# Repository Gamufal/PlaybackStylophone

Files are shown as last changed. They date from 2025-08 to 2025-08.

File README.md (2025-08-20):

# PlaybackStylophone
Stylofon oparty na mikrokontrolerze z możliwością odtworzenia zapisanego wcześniej utworu.

## Cel projektu
Celem jest samodzielne zaprojektowanie i wykonanie własnej wersji stylofonu opartego na mikrokontrolerze, zainspirowanej klasycznym instrumentem elektronicznym z ubiegłego wieku, a jednocześnie wzbogaconej o możliwości, jakie daje współczesna technologia cyfrowa. Realizacja urządzenia ma na celu rozwinięcie umiejętności z zakresu elektroniki, programowania oraz syntezy dźwięku.

## Funkcjonalności:
- Generowanie elektronicznego dźwięku o stałej, syntetycznej barwie
- Regulacja głośności dźwięku
- Regulacja wysokości tonu
- Nagrywanie utworu muzyczneczo
- Odtwarzanie wcześniej nagranej kompozycji
- Zapisywanie ustawień i utworu do pamięci  
- Prezentowanie informacji na wbudowanym wyświetlaczu
- Intuicyjna obsługa ekranu za pomocą przycisków 
- Przenośność dzięki wbudowanemu zasilaniu bateryjnemu
- Szybki start i gotowość do grania po uruchomieniu
- Modułowość umożliwiająca łatwą naprawę w razie uszkodzenia komponentów

## Płytka drukowana
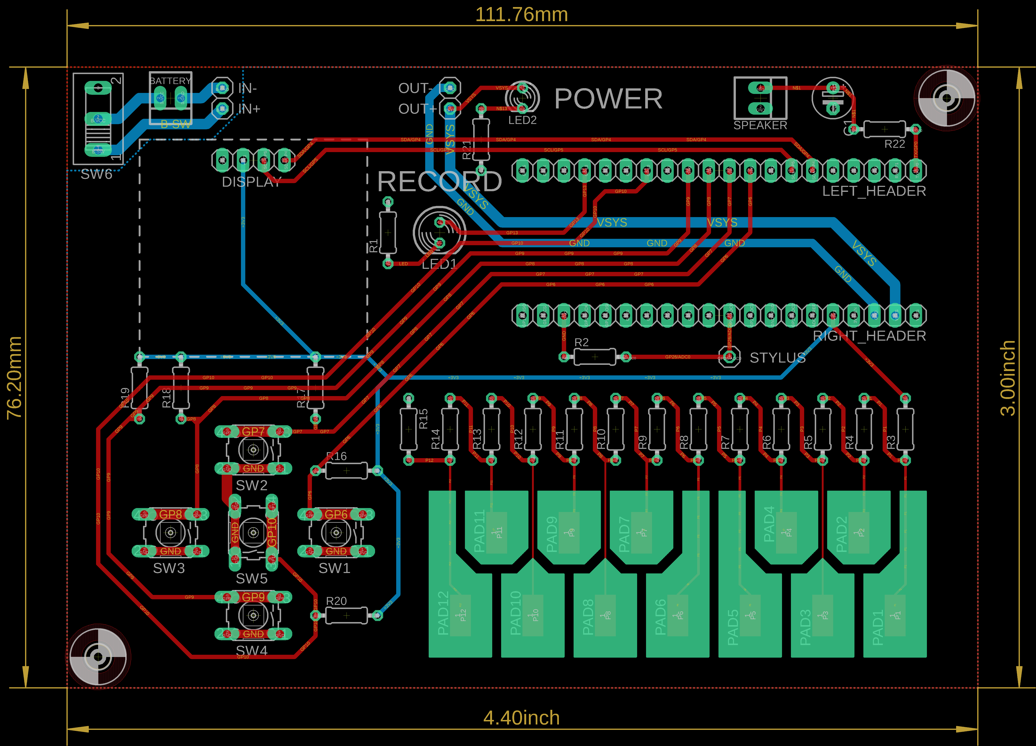
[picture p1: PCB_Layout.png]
PCB Layout


## Mikrokontroler 
Urządzenie wykorzystuje [Raspberry Pi Pico 2](https://www.raspberrypi.com/products/raspberry-pi-pico-2). 

## Kompatybilność
Urządzenie jest kompatybilne z wszystkimi mikrokontrolerami serii Pico od Raspberry Pi. 

## Jak uruchomić urządzenie?
1.	Podłącz baterię 9V typu 6LR61 do gniazda zasilania.
2.	Włącz urządzenie za pomocą przełącznika zlokalizowanego w prawym górnym rogu obudowy.
3.	Po włączeniu:
    - Zapali się zielona dioda LED.
    - Aktywuje się ekran wyświetlacza.
4.	Urządzenie jest gotowe do pracy.
5.	Aby wygenerować dźwięk, dotknij metalowego klawisza przy pomocy stylusu, zostanie odtworzony odpowiedni ton muzyczny.

## Autor
Kamil Kotorc - *Gamufal*

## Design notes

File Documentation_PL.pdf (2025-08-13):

Kamil Kotorc | 31.07.2025

# Stylofon z możliwością nagrywania utworów

## Dokumentacja projektu

### Cel projektu

Celem jest samodzielne zaprojektowanie i wykonanie własnej wersji stylofonu opartego na mikrokontrolerze, zainspirowanej klasycznym instrumentem elektronicznym z ubiegłego wieku, a jednocześnie wzbogaconej o możliwości, jakie daje współczesna technologia cyfrowa. Realizacja urządzenia ma na celu rozwinięcie umiejętności z zakresu elektroniki, programowania oraz syntezy dźwięku.

### Opis głównych założeń projektu

- Stylofon to przenośny instrument muzyczny generujący elektroniczny dźwięk o stałej, syntetycznej barwie, przypominający brzmienie prostych syntezatorów.
- Dzięki wbudowanemu źródłu zasilania, urządzenie jest łatwe do przenoszenia i można je zabrać w dowolne miejsce.
- Instrument wyposażony jest w metalową klawiaturę, która reaguje na nacisk stylusu, zamykając obwód i generując dźwięk.
- Stylofon umożliwia regulację wysokości dźwięku, co daje użytkownikowi większą swobodę twórczą.
- Użytkownik ma możliwość nagrywania swoich utworów muzycznych oraz ich późniejszego odtwarzania.
- Mały wyświetlacz zwiększa intuicyjność obsługi urządzenia, ułatwiając korzystanie z jego funkcji.
- Urządzenie jest zasilane bateryjnie, co eliminuje konieczność stałego podłączenia do źródła prądu.

Copyright: © 2025 Kamil Kotorc | 1

## Spis treści

# Wybór elementów elektronicznych

## Mikrokontroler

Większość z wymienionych mikrokontrolerów byłaby odpowiednia do realizacji tego projektu, jednak należy zwrócić uwagę na kilka kluczowych aspektów. ESP32, choć oferuje największą moc obliczeniową, charakteryzuje się stosunkowo wysokim zużyciem energii, co ogranicza jego czas pracy na baterii. Układy Arduino są relatywnie drogie, Mega oferuje nieznacznie większe możliwości niż wersja Nano, głównie w zakresie liczby pinów GPIO, które nie są tak ważne w tym projekcie. Mój wybór padł na Raspberry Pi Pico 2 ze głównie ze względu na sporą uniwersalność. Cechuje się dobrymi parametrami, obsługiwanymi interfejsami oraz 12-bit rozdzielczością ADC, który jest ważnym elementem projektu. Ponadto stosunek jakości do ceny jest zadowalający.

## Wyświetlacz

Postanowiłem użyć wyświetlacza typu OLED. Jego główną zaletą jest dobra rozdzielczość w stosunku do jego małych rozmiarów, przez co idealnie wpasuje się w urządzenie. Dodatkowo jest tani i wymaga tylko 2 pinów do komunikacji z mikrokontrolerem, a jego niski czas odświeżania przełoży się na lepszą responsywność urządzenia. Także w stosunku do innych wyświetlaczy posiada dobry kontrast, a co za tym idzie oferuje dobrą czytelność o każdej porze dnia.

## Przetwornica napięcia

Zastosowałem popularny układ LM2596. Cechuje się wysoką sprawnością, co wydłuży pracę na baterii. Dodatkowo posiada zabezpieczenia chroniące urządzenie oraz wystarczającą moc do zasilania urządzenia. Występuje także w wielu konfiguracjach, w szczególności wersje o małych rozmiarach.

## Metalowa klawiatura

Wzorując się na oryginalnym stylofonie, stwierdziłem, że dobrym rozwiązaniem będzie wykorzystanie drabinki rezystorowej i odczytywanie różnicy spadku napięcia względem napięcia referencyjnego. Wadą tej metody jest niepowtarzalność otrzymywanych wartości napięć, co należy uwzględnić podczas programowania. Zaletą jest natomiast to, że wymaga ona użycia jedynie jednego portu analogowego. Wybrany mikrokontroler posiada 12-bit ADC, który bez problemu dokładnie zmierzy wartości odpowiadające każdemu klawiszowi. Same klawisze można stworzyć poprzez rozdzielenie powierzchni na płytce na poszczególne klawisze. Do tego posłużyła mi miedziana płytka do wytrawiania.

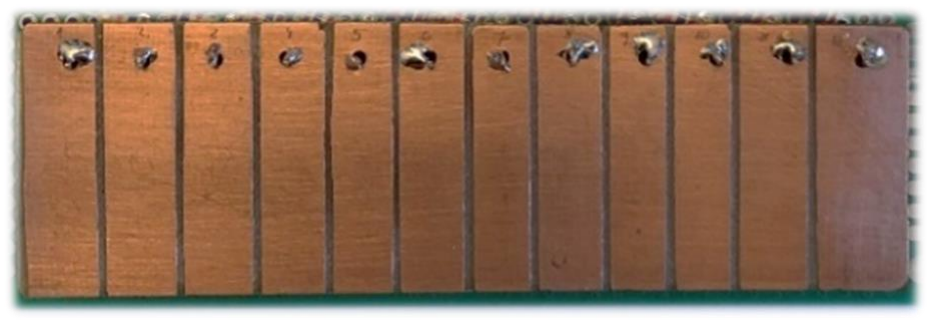
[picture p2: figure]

PROTOTYPOWA KLAWIATURA WYKONANA NA LAMINACIE 1,6MM

# Specyfikacja wewnętrzna urządzenia

## Generowanie dźwięku

Wstęp
Stylofon pierwotnie wyprodukowany w Wielkiej Brytanii w 1968 roku. Opierał się na programowalnym tranzystorze jednozłączowym UJT, który nadawał jego unikalne brzmienie. W latach 70-tych całkowicie zastąpiono oscylatory relaksacyjne prostszymi i tańszymi generatorami tonów prostokątnych opartymi na timerze 555.
Wersja z UJT
Układ oparty na tranzystorze jednozłączowym, ma zalety głównie w postaci otrzymywanego charakterystycznego i oryginalnego brzmienia, a sama konstrukcja nie jest stosunkowo skomplikowana.

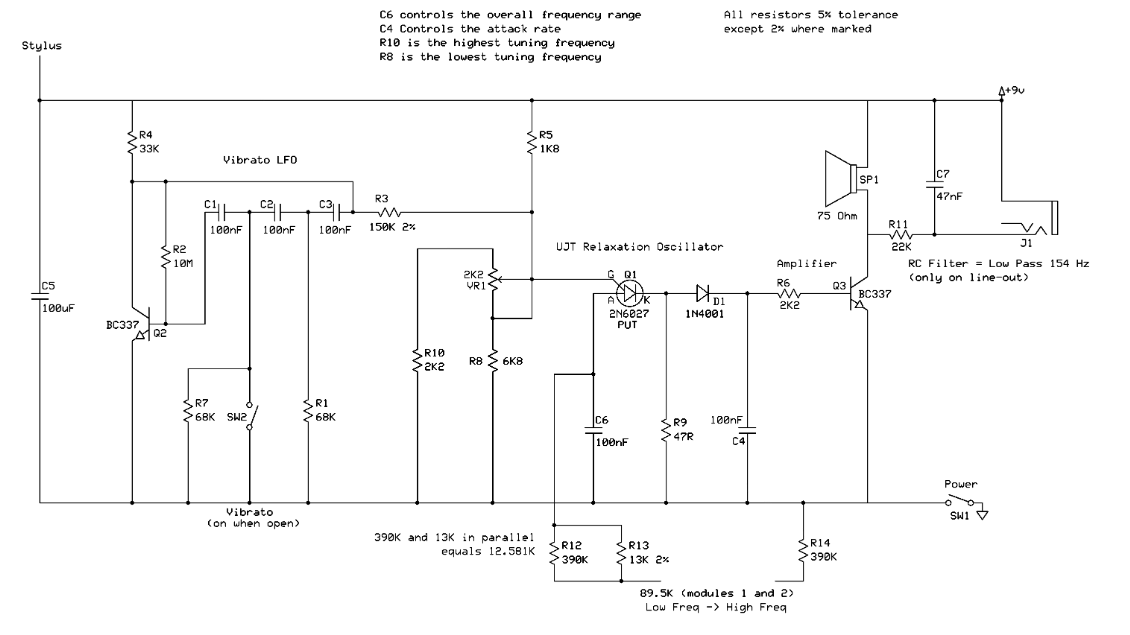
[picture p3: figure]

SCHEMAT ORYGINALNEGO STYLOFONU Z 1968

Jednak rozwiązanie to ma też swoje wady.
Oscylatory z tranzystorami jednozłączowymi są bardziej podatne na zmiany częstotliwości wynikające z wahań napięcia zasilania oraz tolerancji elementów pasywnych, co utrudnia precyzyjne dostrajanie generowanej częstotliwości bez specjalistycznego sprzętu, takiego jak oscyloskop.
UJT nie generuje sygnału o prostokątnym kształcie, co może wymagać zastosowania dodatkowych układów dopasowujących, aby przetwornik analogowo-cyfrowy mikrokontrolera mógł prawidłowo interpretować sygnał wejściowy.
Także rynek elektroniczny mocno się rozwinął, co za tym idzie dobranie odpowiedniego tranzystora jednozłączowego staje się trudniejsze, ponieważ wiele układów w nowszej technologii wyparło je z rynku.

Wersja z timerem 555
Nowsze rozwiązania są oparte na timerze 555, który jest jednym z najpopularniejszych i najbardziej wszechstronnych układów, które kiedykolwiek wyprodukowano. Częstotliwość oscylacji jest regulowana, a możliwe jest nawet dodanie różnych efektów, gdyż układ jest w stanie generować różne kształty fali.

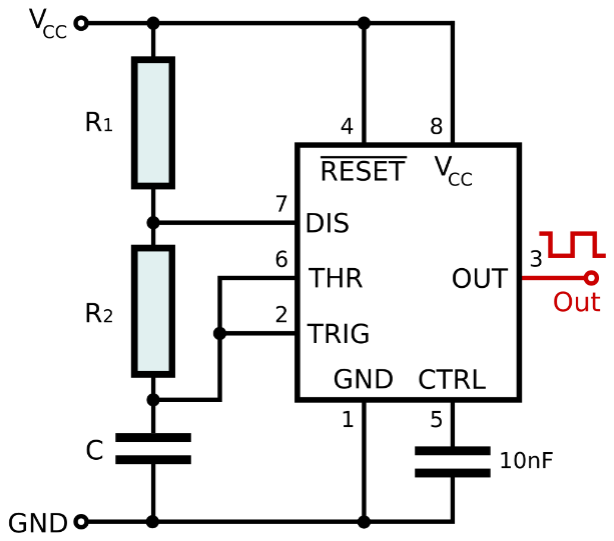
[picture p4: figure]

SCHEMAT UKŁADU ASTABILNEGO

Mimo tych zalet rozwiązanie to ma swoje ograniczenia. Nadal wymagana jest integracja z mikrokontrolerem, w celu odczytania generowanej częstotliwości. Timer 555 operuje na napięciu od 4.5 do 16 wolt, co może okazać się zbyt wysokim napięciem dla przetworników ADC większości mikrokontrolerów, bez zastosowania układów redukujących napięcie. Również z poziomu mikrokontrolera nie możemy cyfrowo sterować jaka częstotliwość powinna być wygenerowana w 555, gdyż ta zależna jest od rezystancji pomiędzy jego pinami.
Wersja PWM
Zamiast korzystać z dedykowanych układów, większość mikrokontrolerów pozwala na generowanie fali prostokątnej za pomocą sygnału PWM. Wybrałem zatem takie rozwiązanie, bo znacząco upraszcza konstrukcję, a częstotliwość i wypełnienie sygnału można sterować programowo.

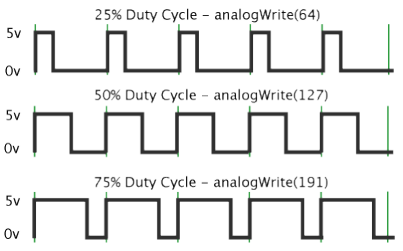
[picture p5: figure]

SYGNAŁ GENEROWANY PRZY UŻYCIU PWM

Wadą tego rozwiązania jest jednak jakość generowanych tonów, ponieważ funkcja PWM nie jest zoptymalizowana pod kątem sygnałów audio. Niemożliwe jest też wytworzenie innych kształtów fali niż prostokątna samym mikrokontrolerem. Natomiast jakość dźwięku nie będzie tutaj problemem.

## Schemat blokowy

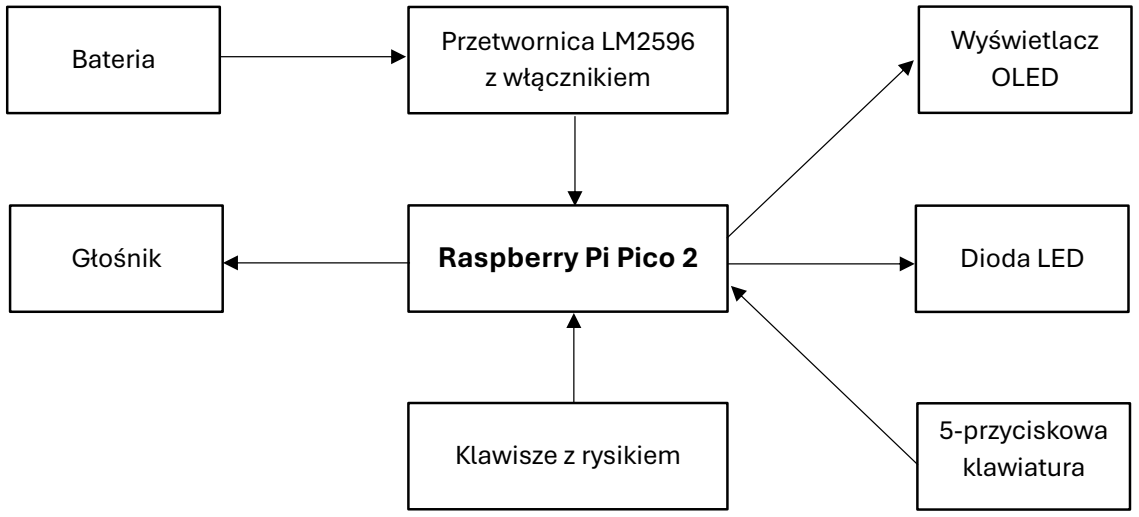
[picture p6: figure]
Wyświetlacz OLED; 5-przyciskowa klawiatura; Raspberry Pi Pico 2; Klawisze z rysikiem; Bateria; Przetwornica LM2596; z włącznikiem; Głośnik; Dioda LED

Opis poszczególnych bloków
Raspberry Pi Pico 2 – Serce urządzenia, odpowiedzialne za przetwarzanie danych wejściowych i wyjściowych, generowanie sygnału dźwiękowego oraz integrację wszystkich elementów urządzenia. Przechowuje dane, takie jak ustawienia, pamięć programu oraz zapisane utwory. Wyświetlacz OLED – Jedno-calowy wyświetlacz odpowiedzialny za prezentowanie informacji z mikrokontrolera oraz komunikację z użytkownikiem. Zwiększa intuicyjność obsługi urządzenia i wyświetla menu z różnymi opcjami.
Dioda LED – Czerwona dioda, która zwiększa intuicyjność obsługi urządzenia. Migocze podczas nagrywania, a świeci na stałe podczas odtwarzania utworów, dopełniając wyświetlacz. 5-przyciskowa klawiatura – Umożliwia zbieranie danych od użytkownika i służy do nawigacji po elementach wyświetlanych na ekranie OLED.
Klawisze z rysikiem – Po zetknięciu zamykają obwód, przesyłając do mikrokontrolera informację o naciśniętym klawiszu.
Głośnik – Mimo niewielkiej mocy (1W), generuje wyraźny dźwięk, przesyłany z mikrokontrolera. Bateria – Standardowa bateria 9V stanowi główne źródło zasilania urządzenia. Dzięki dwóm charakterystycznym wejściom jest łatwa do wymiany, a przy tym kompaktowa.
Przetwornica LM2596 – Obniża napięcie z 9V do 3,3V, akceptowalnego przez mikrokontroler, i zasila pozostałe elementy znajdujące się na płytce.

## Schemat ideowy

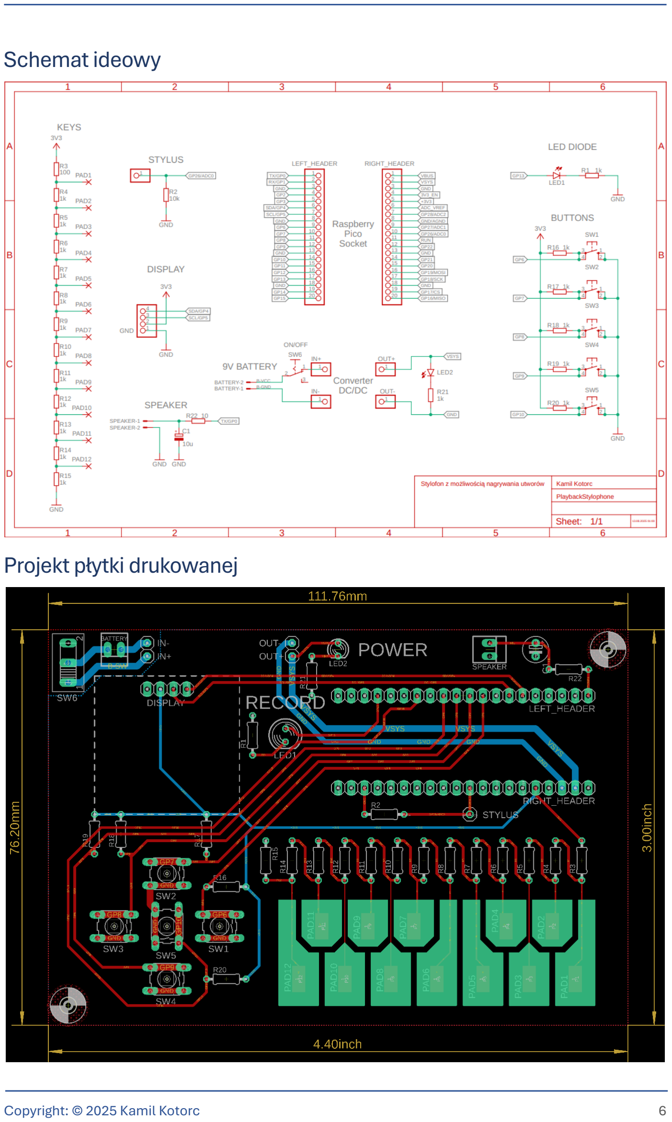
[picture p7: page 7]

## Projekt płytki drukowanej

## Lista elementów

NAZWA | ILOŚĆ
Raspberry Pi Pico 2 | 1
Dioda LED 5mm | 2
Rezystor 1/4W 1kΩ | 21
Rezystor 1/4W 10kΩ | 1
Wyświetlacz OLED 0,96'' | 1
Przetwornica step-down LM2596 | 1
Tact Switch 6x6mm | 5
Złącza damskie goldpin | 5
Mikroprzełącznik bistabilny | 1
Bateria 9V 4022 6LR61 | 1
Głośnik 1W 8Ohm | 1

## Oprogramowanie urządzenia

Algorytm działania oprogramowania
Oprogramowanie stylofonu działa w pętli głównej, zarządza dźwiękiem, wyświetlaczem oraz interakcją z użytkownikiem. Pozwala na zmianę parametrów, nagrywanie oraz odtwarzanie dźwięków.
Główne etapy działania to:
1. Inicjalizacja urządzeń peryferyjnych:
- OLED
- Przyciski
- ADC
- PWM
- dioda LED
2. Wczytanie zapisanych ustawień z pliku settings.json.
3. Uruchomienie pętli menu głównego, pozwalającej użytkownikowi na wybór opcji.
4. Obsługa wybranych funkcji:
- Regulacja głośności
- Zmiana oktawy
- Nagrywanie dźwięku
- Odtwarzanie nagrania
5. Dynamiczne odtwarzanie dźwięków na podstawie wartości z czujnika ADC.
6. Zapis ustawień do pliku.

Opis zmiennych
volume – Poziom głośności (zakres 1-8).
tone – Wybór oktawy (1 – dolna, 2 – środkowa, 3 – górna).
recording – Lista przechowująca zapisane dźwięki w postaci par (częstotliwość, czas). adc_thresholds – Progi wartości ADC dla przypisania konkretnej nuty.

lower_octave, middle_octave, higher_octave – Tablice częstotliwości dźwięków dla
różnych oktaw.

Opis funkcji
save_single_setting(key, value) – Zapisuje pojedyncze ustawienie do pliku settings.json.
load_settings() – Wczytuje ustawienia zapisane w settings.json, jeśli plik istnieje. get_note_index(adc_val) – Na podstawie wartości ADC zwraca indeks odpowiadający konkretnej nucie.
get_note_from_index(idx) – Zwraca częstotliwość dźwięku na podstawie indeksu i aktualnej oktawy.
update_live_audio() – Odczytuje wartość ADC i generuje odpowiadający jej dźwięk poprzez PWM.
display_menu(selected_item) – Wyświetla główne menu na ekranie OLED, podświetlając wybraną opcję.
volume_menu() – Obsługuje zmianę głośności i zapisuje ustawienie.
tone_menu() – Obsługuje zmianę oktawy i zapisuje ustawienie.
record_menu() – Nagrywa dźwięki grane na stylofonie, zapisując je w tablicy recording. play_menu() – Odtwarza zapisane dźwięki poprzez generowanie odpowiednich częstotliwości PWM.
main() – Główna pętla obsługująca nawigację po menu oraz reakcję na wybór użytkownika.

Szczegółowy opis kluczowej procedury

update_live_audio()
1. Odczytuje wartość ADC.
2. Sprawdza, czy wartość ADC odpowiada progowi nuty.
3. Jeśli tak, odczytuje częstotliwość z aktualnie wybranej oktawy.
4. Ustawia częstotliwość PWM na wyliczoną wartość.
5. Jeśli nie, wyłącza sygnał PWM.

# Specyfikacja zewnętrzna urządzenia

## Zdjęcie gotowego prototypu urządzenia

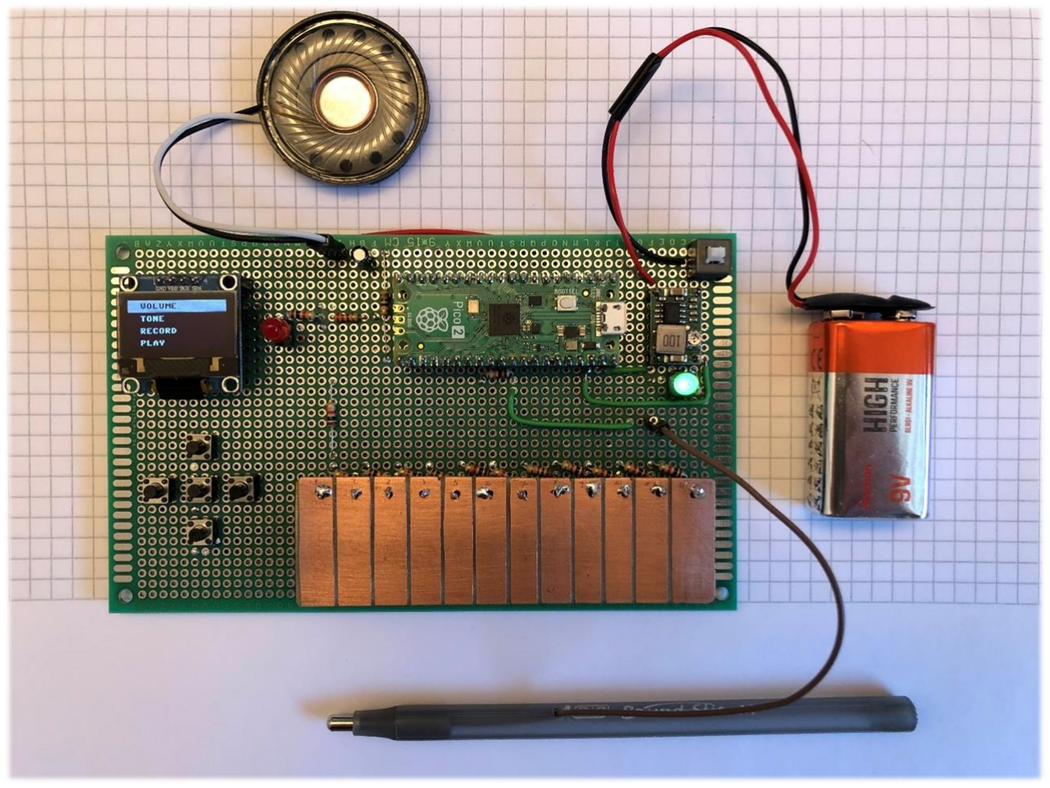
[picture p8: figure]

## Elementy sterujące

- 5-przyciskowa klawiatura w lewym dolnym rogu urządzenia
- Metalowe klawisze z stylusem w dolnej części urządzenia
- Włącznik urządzenia w prawym górnym rogu

## Elementy wykonawcze

- Wyświetlacz OLED po lewej stronie
- Czerwona dioda po prawej od wyświetlacza
- Zielona dioda w prawej części urządzenia
- Głośnik 1W znajdujący się w górnej części urządzenia

## Reakcja oprogramowania

Tabela przedstawiająca zachowanie urządzenia w odpowiedzi na działania użytkownika

Działanie użytkownika | Reakcja urządzenia
Włączenie urządzenia przełącznikiem | Zapala się zielona dioda LED
Dotknięcie metalowego klawisza stylusem | Wygenerowanie odpowiedniego tonu dźwiękowego
Naciśnięcie przycisku funkcyjnego | W zależności od przycisku:
- Nawigacja po menu
- Wybór opcji z menu
- Cofnięcie do menu głównego
- Ustawienie poziomu tonu lub głośności
- Rozpoczęcie nagrywania lub odtwarzania
Rozpoczęcie nagrywania utworu | Czerwona dioda miga
Rozpoczęcie odtwarzania nagranego utworu | Czerwona dioda świeci ciągłym światłem do końca odtwarzania

## Instrukcja obsługi urządzenia

Uruchomienie urządzenia
1. Podłącz baterię 9V typu 6LR61 do gniazda zasilania.
2. Włącz urządzenie za pomocą przełącznika zlokalizowanego w prawym górnym rogu obudowy.
3. Po włączeniu:
- Zapali się zielona dioda LED.
- Aktywuje się ekran wyświetlacza.
4. Urządzenie jest gotowe do pracy.
5. Aby wygenerować dźwięk, dotknij metalowego klawisza przy pomocy stylusu, zostanie odtworzony odpowiedni ton muzyczny.
Obsługa menu
Przycisk | Funkcja
Góra / Dół | Przejście do kolejnej/poprzedniej pozycji menu; cofnięcie do menu głównego.
Lewo / Prawo | Zmiana wartości parametru (głośność / tonacja).
Środkowy (OK) | Zatwierdzenie wyboru; uruchomienie funkcji (nagrywanie / odtwarzanie).

Potencjalne usterki i sposoby naprawy

Objaw | Możliwa przyczyna | Sugerowane rozwiązanie
Ekran działa, zielona dioda nie świeci | Przepalona zielona dioda LED | Wymień diodę na nową
Zielona dioda świeci, ekran nie działa | Uszkodzony moduł wyświetlacza | Sprawdź połączenia, w razie potrzeby wymień wyświetlacz
Ekran i zielona dioda nie działają | Rozładowana bateria 9V | Wymień baterię na nową
Dioda i ekran działają, ale urządzenie nie wydaje dźwięku | Uszkodzony głośnik lub jego połączenie | Sprawdź przewody głośnika lub wymień głośnik

## Programowanie układu

Programowanie układu następuje poprzez wpięcie kabla micro-USB do mikrokontrolera oraz podłączenie do komputera przy jednoczesnym trzymaniu przycisku BOOTSEL na mikrokontrolerze.

## Testowanie

Przed wykonaniem finalnej wersji urządzenia, stylofon został przetestowany na płytce prototypowej. Proces testowania obejmował następujące etapy:
1. Testowanie połączeń elektrycznych – Sprawdzono poprawność podłączenia wszystkich elementów. Wykorzystano multimetr do weryfikacji ciągłości obwodów i poprawnego doprowadzenia napięcia do poszczególnych komponentów.
2. Weryfikacja działania klawiatury i rysika – Testowano reakcję mikrokontrolera na naciśnięcie przycisków oraz dotknięcie rysikiem klawiszy. Sprawdzano, czy każda akcja skutkuje generowaniem odpowiedniego dźwięku.
3. Testowanie wyświetlacza OLED – Zweryfikowano poprawność komunikacji z mikrokontrolerem, wyświetlanie informacji oraz responsywność zmian w menu.
4. Sprawdzenie działania głośnika – Podawano różne częstotliwości dźwięku, aby upewnić się, że głośnik poprawnie generuje wymagane dźwięki.
5. Analiza pracy diody LED – Testowano miganie oraz ciągłe świecenie diody w zależności od aktywnego trybu pracy urządzenia.
6. Zasilanie i stabilność układu – Monitorowano pobór prądu oraz stabilność działania układu przy różnych obciążeniach. Testowano także wydajność przetwornicy LM2596, oraz wyregulowano ją do obniżenia napięcia do 3.32V.

# Odnośniki

- Strona projektu na GitHub (https://github.com/Gamufal/PlaybackStylophone)

# Literatura

Raspberry Pi Pico 2 Datasheet: An RP2350-based microcontroller board.
- © 2023-2024 Raspberry Pi Ltd

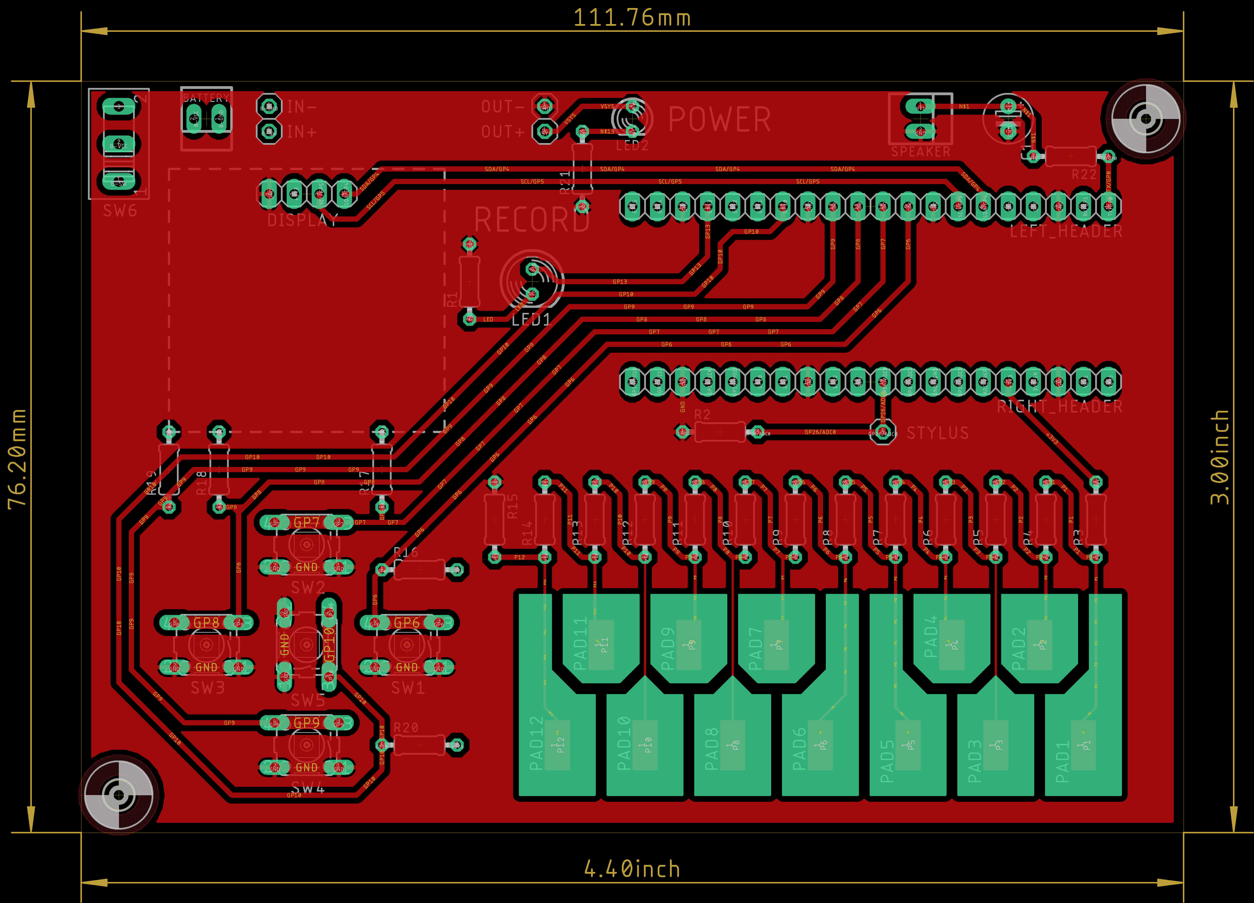
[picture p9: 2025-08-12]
PCB_TopLayer_Design.png

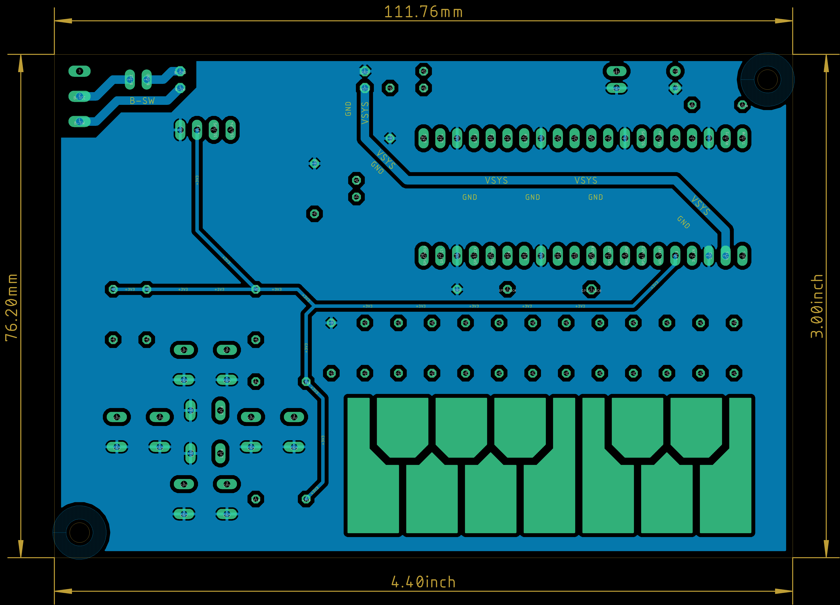
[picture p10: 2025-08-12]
PCB_BottomLayer_Design.png

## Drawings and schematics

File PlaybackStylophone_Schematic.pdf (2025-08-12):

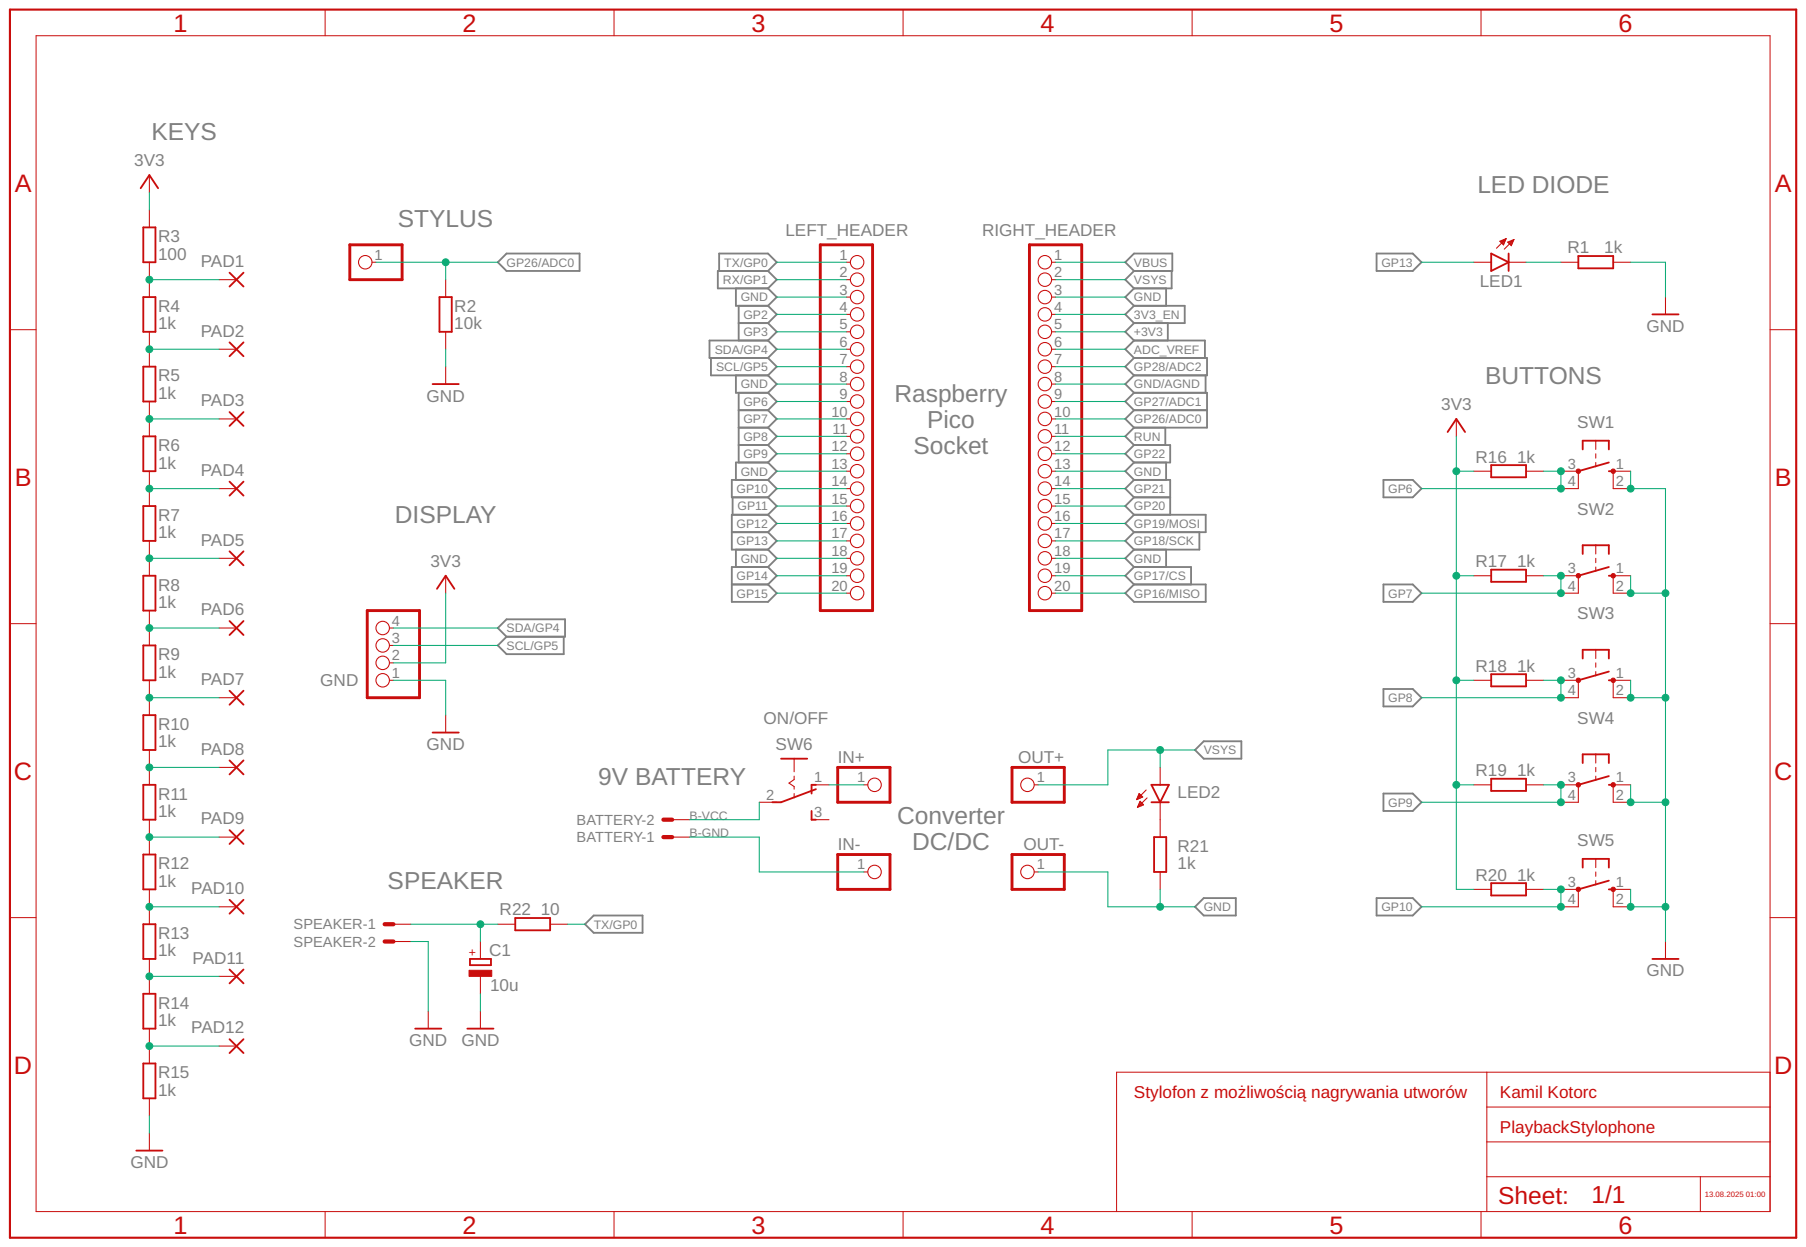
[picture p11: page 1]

RX/GP1 GP2 GP3 SDA/GP4
GND GND

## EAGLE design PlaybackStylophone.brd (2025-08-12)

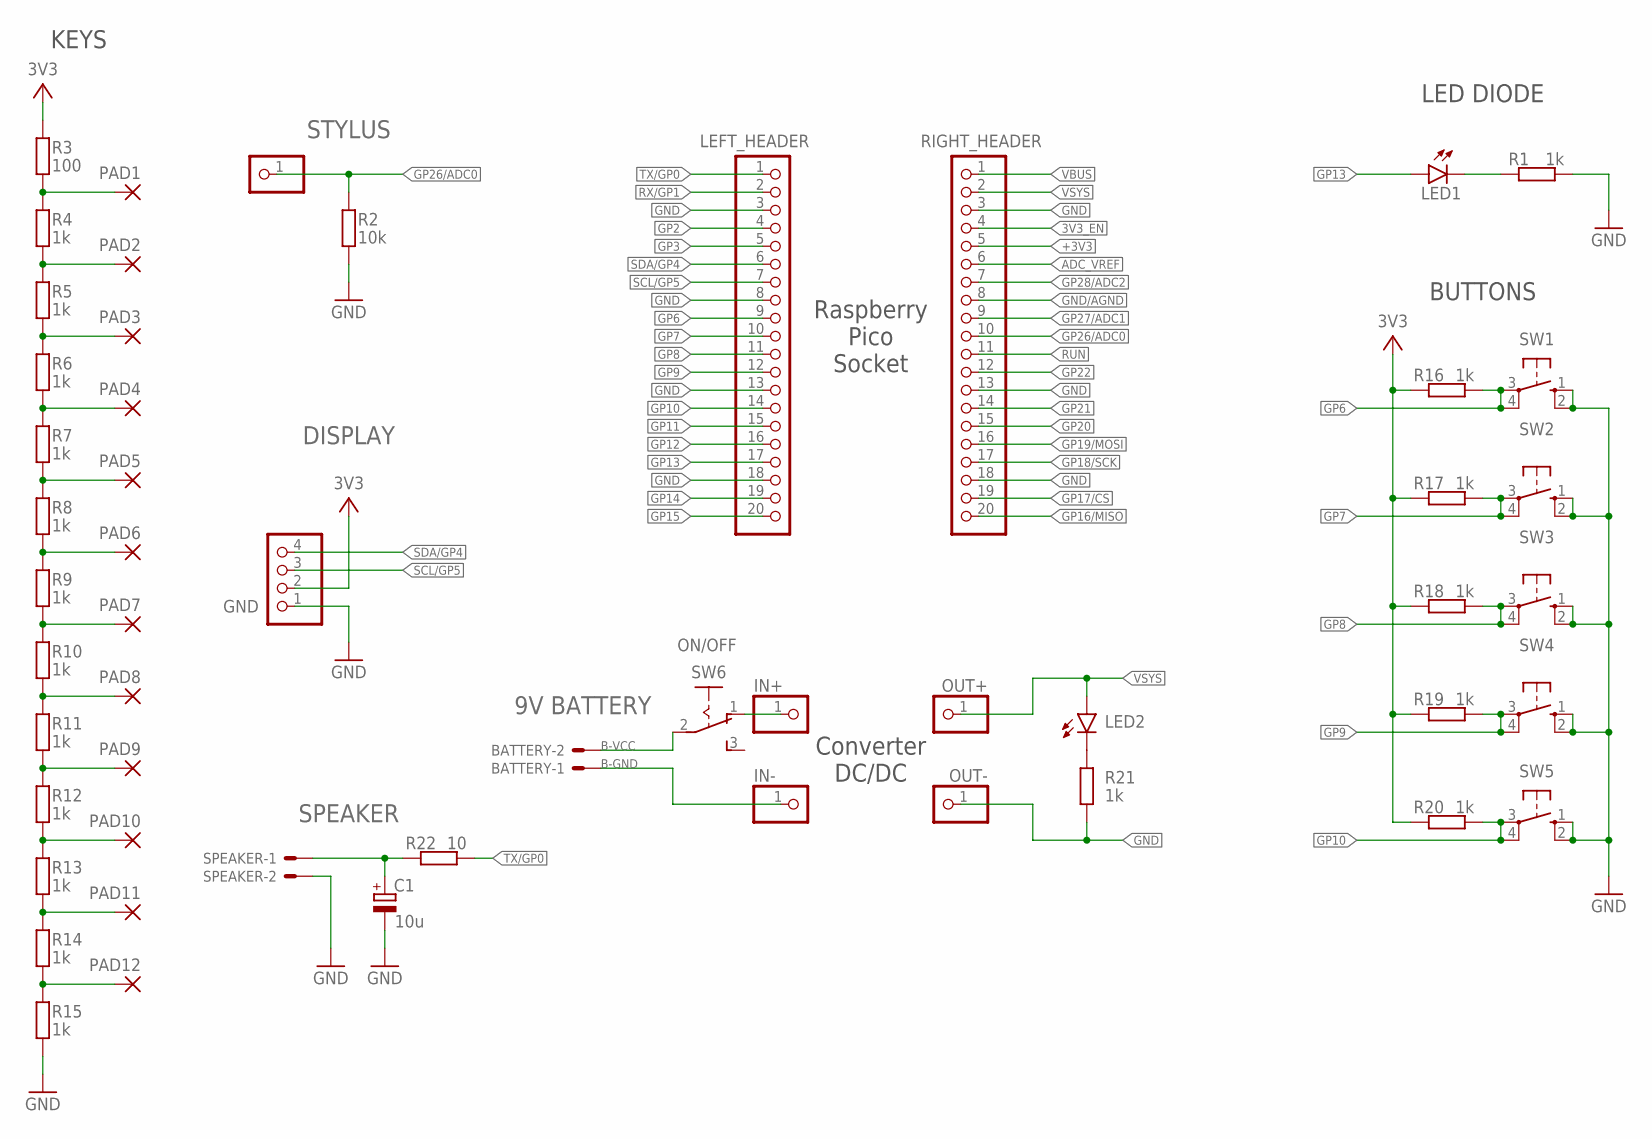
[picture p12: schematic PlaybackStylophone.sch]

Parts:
BATTERY: 9V BATTERY; 22-23-2021
C1: 10u; E2,5-5
DISPLAY: GND; 1X04
IN+: PINHD-1X1; 1X01
IN-: PINHD-1X1; 1X01
LED1: LED5MM
LED2: LED3MM
LEFT_HEADER: PINHD-1X20; 1X20
OUT+: PINHD-1X1; 1X01
OUT-: PINHD-1X1; 1X01
PAD1, PAD2, PAD3, PAD4, PAD5, PAD6, PAD7, PAD8, PAD9, PAD10, PAD11, PAD12: SMD5; SMD2,54-5,08
R1, R4, R5, R6, R7, R8, R9, R10, R11, R12, R13, R14, R15, R16, R17, R18, R19, R20, R21: 1k; 0204/7
R2: 10k; 0204/7
R3: 100; 0204/7
R22: 10; 0204/7
RIGHT_HEADER: PINHD-1X20; 1X20
SPEAKER: SPEAKER; 22-23-2021
STYLUS: PINHD-1X1; 1X01
SW1, SW2, SW3, SW4, SW5: 10-XX; B3F-10XX
SW6: ON/OFF; 255SB

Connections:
3V3_EN: RIGHT_HEADER.4
+3V3: DISPLAY.2, R3.2, R16.2, R17.2, R18.2, R19.2, R20.2, RIGHT_HEADER.5
ADC_VREF: RIGHT_HEADER.6
B-GND: BATTERY.1, IN-.1
B-SW: IN+.1, SW6.1 (O)
B-VCC: BATTERY.2, SW6.2
GND: C1.-, DISPLAY.1, LEFT_HEADER.3, LEFT_HEADER.8, LEFT_HEADER.13, LEFT_HEADER.18, OUT-.1, R1.1, R2.1, R15.1, R21.1, RIGHT_HEADER.3, RIGHT_HEADER.13, RIGHT_HEADER.18, SPEAKER.2, SW1.1 (S), SW1.2 (S1), SW2.1 (S), SW2.2 (S1), SW3.1 (S), SW3.2 (S1), SW4.1 (S), SW4.2 (S1), SW5.1 (S), SW5.2 (S1)
GND/AGND: RIGHT_HEADER.8
GP2: LEFT_HEADER.4
GP3: LEFT_HEADER.5
GP6: LEFT_HEADER.9, R16.1, SW1.3, SW1.4 (P1)
GP7: LEFT_HEADER.10, R17.1, SW2.3, SW2.4 (P1)
GP8: LEFT_HEADER.11, R18.1, SW3.3, SW3.4 (P1)
GP9: LEFT_HEADER.12, R19.1, SW4.3, SW4.4 (P1)
GP10: LEFT_HEADER.14, R20.1, SW5.3, SW5.4 (P1)
GP11: LEFT_HEADER.15
GP12: LEFT_HEADER.16
GP13: LED1.A, LEFT_HEADER.17
GP14: LEFT_HEADER.19
GP15: LEFT_HEADER.20
GP16/MISO: RIGHT_HEADER.20
GP17/CS: RIGHT_HEADER.19
GP18/SCK: RIGHT_HEADER.17
GP19/MOSI: RIGHT_HEADER.16
GP20: RIGHT_HEADER.15
GP21: RIGHT_HEADER.14
GP22: RIGHT_HEADER.12
GP26/ADC0: R2.2, RIGHT_HEADER.10, STYLUS.1
GP27/ADC1: RIGHT_HEADER.9
GP28/ADC2: RIGHT_HEADER.7
LED: LED1.K (C), R1.2
unnamed: C1.+, R22.2, SPEAKER.1
unnamed: LED2.K (C), R21.2
P1: PAD1.1, R3.1, R4.2
P2: PAD2.1, R4.1, R5.2
P3: PAD3.1, R5.1, R6.2
P4: PAD4.1, R6.1, R7.2
P5: PAD5.1, R7.1, R8.2
P6: PAD6.1, R8.1, R9.2
P7: PAD7.1, R9.1, R10.2
P8: PAD8.1, R10.1, R11.2
P9: PAD9.1, R11.1, R12.2
P10: PAD10.1, R12.1, R13.2
P11: PAD11.1, R13.1, R14.2
P12: PAD12.1, R14.1, R15.2
RUN: RIGHT_HEADER.11
RX/GP1: LEFT_HEADER.2
SCL/GP5: DISPLAY.3, LEFT_HEADER.7
SDA/GP4: DISPLAY.4, LEFT_HEADER.6
TX/GP0: LEFT_HEADER.1, R22.1
VBUS: RIGHT_HEADER.1
VSYS: LED2.A, OUT+.1, RIGHT_HEADER.2

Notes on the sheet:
Raspberry Pico Socket
KEYS
LED DIODE
BUTTONS
Converter DC/DC

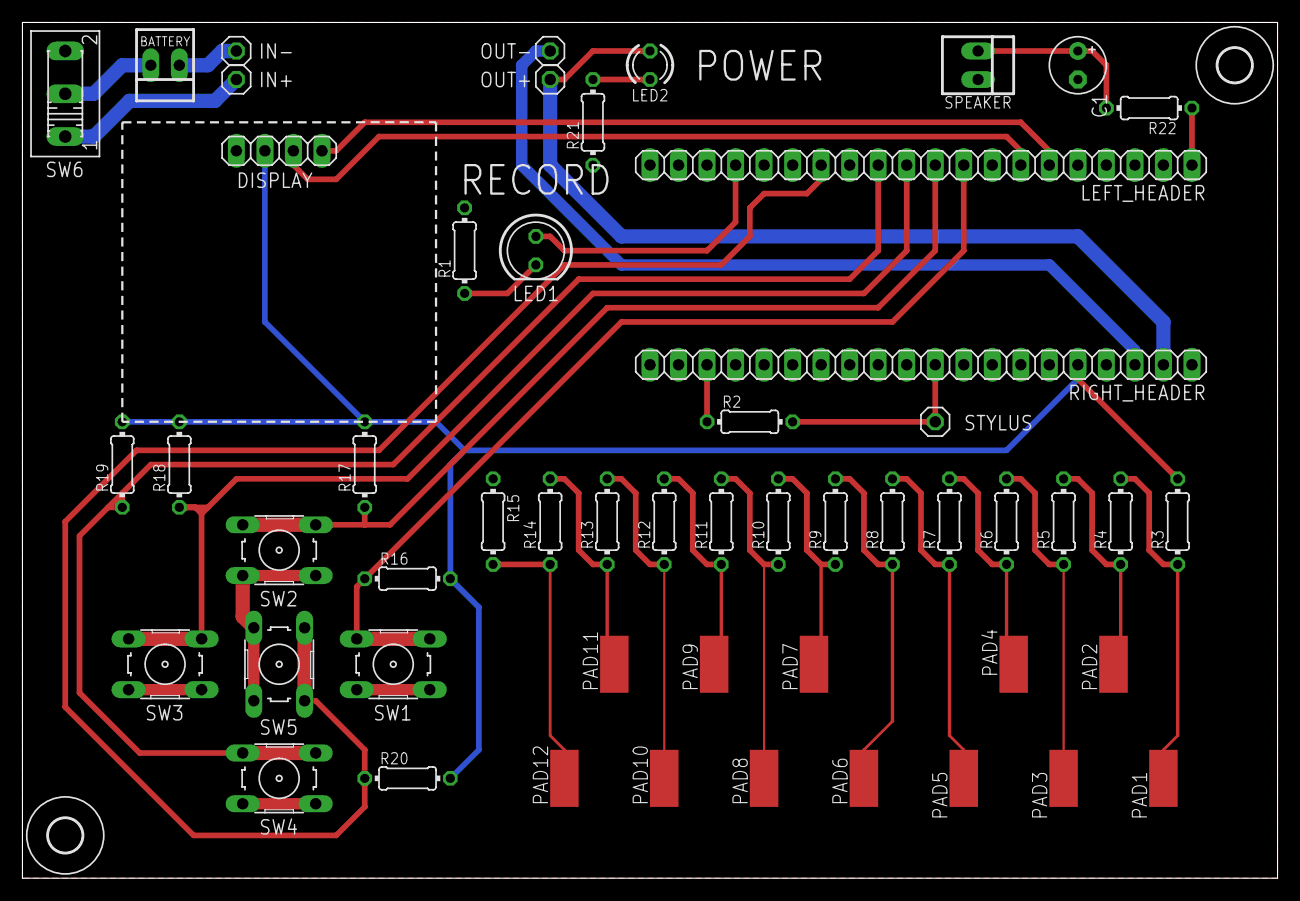
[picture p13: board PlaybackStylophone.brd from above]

Board: 2 copper layers, 111.8 x 76.2 mm, 55 parts (0 on the bottom side), 31 nets.

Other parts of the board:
U$1, U$2: 3,0

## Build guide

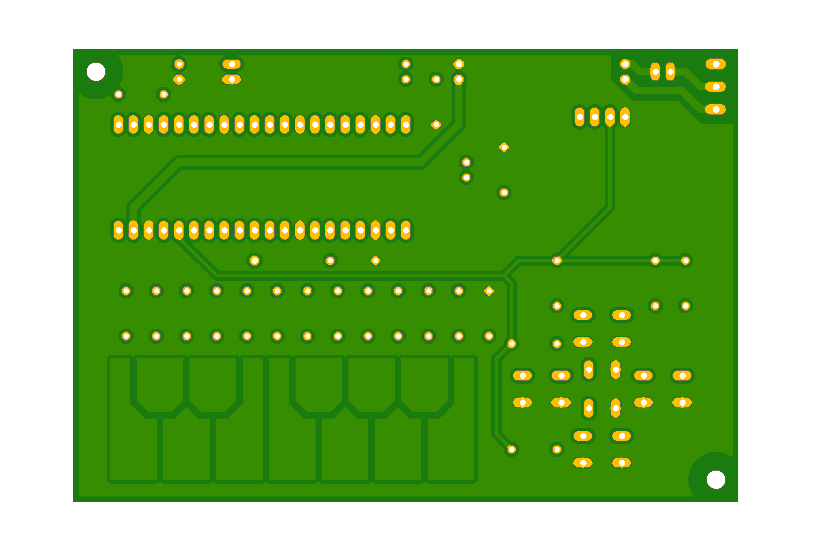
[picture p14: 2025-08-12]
PCB_BottomLayer_Manufacture.png

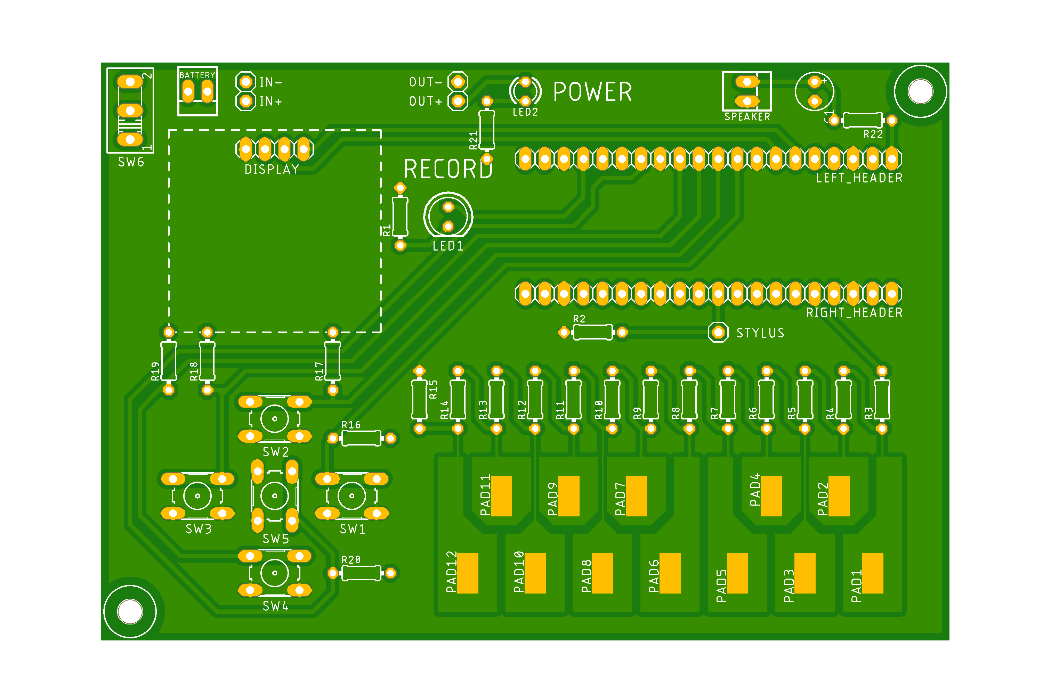
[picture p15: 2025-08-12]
PCB_TopLayer_Manufacture.png

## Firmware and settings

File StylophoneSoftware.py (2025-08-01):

# Software for Playback Stylophone 
# Made by Gamufal
# Version: 25.8.1

from machine import Pin, ADC, I2C, PWM
import ssd1306
import json
from time import sleep, time

# Initialization of OLED Display (128x64)
i2c = I2C(0, sda=Pin(4), scl=Pin(5), freq=400000)
display = ssd1306.SSD1306_I2C(128, 64, i2c)

# LED diode initialization
led = Pin(13, Pin.OUT)

# Buttons initialization 
btn_down  = Pin(6,  Pin.IN, Pin.PULL_UP)
btn_up    = Pin(8,  Pin.IN, Pin.PULL_UP)
btn_right = Pin(7,  Pin.IN, Pin.PULL_UP)
btn_left  = Pin(9,  Pin.IN, Pin.PULL_UP)
btn_ok    = Pin(10, Pin.IN, Pin.PULL_UP)

# ADC Initialization for stylus 
adc = ADC(Pin(26))
adc_thresholds = [4500, 9000, 13000, 17000, 20000, 24000, 29000, 34000, 39000, 46000, 54000, 64000]

# PWM Initialization for the speaker
spk = PWM(Pin(16))
spk.duty_u16(0)

# Three sets of notes:
lower_octave  = [131, 139, 147, 156, 165, 175, 185, 196, 208, 220, 233, 247]
middle_octave = [261, 277, 293, 311, 329, 349, 369, 392, 415, 440, 466, 493]
higher_octave = [523, 554, 587, 622, 659, 698, 739, 784, 830, 880, 932, 987]

# Global settings
volume = 4   # 1-8
tone = 2     # 1-3
recording = []  # (freq, timestamp), ...

# Saves a single setting to a JSON file
def save_single_setting(key, value):
    try:
        with open("settings.json", "r") as f:
            settings = json.load(f)
    except (OSError, ValueError):
        settings = {}
    settings[key] = value
    with open("settings.json", "w") as f:
        json.dump(settings, f)
    print(f"Saved {key}: {value}")

# Loads saved settings from a JSON file
def load_settings():
    global volume, tone, recording
    try:
        with open("settings.json", "r") as f:
            settings = json.load(f)
            volume = settings.get("volume", 4)
            tone = settings.get("tone", 2) 
            recording = settings.get("recording", [])  
        print("Settings loaded!")
    except Exception as e:
        print("No settings found, using defaults.", e)

# Returns the index of the note based on the ADC value
def get_note_index(adc_val):
    idx = -1
    for i in range(len(adc_thresholds)):
        if adc_val >= adc_thresholds[i]:
            idx = i
        else:
            break
    return idx if idx != -1 else None

# Retrieves the note frequency from the index and currently selected octave
def get_note_from_index(idx):
    global tone
    if tone == 1:
        return lower_octave[idx]
    elif tone == 2:
        return middle_octave[idx]
    elif tone == 3:
        return higher_octave[idx]

# Updates the speaker output in real time based on the ADC reading
def update_live_audio():
    adc_val = adc.read_u16()
    idx = get_note_index(adc_val)
    if idx is not None:
        freq = get_note_from_index(idx)
        spk.freq(freq)
        spk.duty_u16(volume * 4096)
    else:
        spk.duty_u16(0)

# Displays the main menu
def display_menu(selected_item):
    menu_items = ["VOLUME", "TONE", "RECORD", "PLAY"]
    display.fill(0)
    for i, item in enumerate(menu_items):
        y = i * 16
        if i == selected_item:
            display.fill_rect(0, y, 128, 16, 1)  
            display.text(item, 16, y + 4, 0)      
        else:
            display.text(item, 16, y + 4, 1)      
    display.show()

# Handles volume adjustment
def volume_menu():
    global volume
    display.fill(0)
    display.text("VOLUME", 16, 30, 1)
    display.text(str(volume), 104, 30, 1)
    bar_width = int(volume * 96 / 8)
    display.fill_rect(16, 45, bar_width, 10, 1)
    display.show()
    while True:
        update_live_audio()
        if btn_left.value() == 0 and volume > 1:
            volume -= 1
            display.fill(0)
            display.text("VOLUME", 16, 30, 1)
            display.text(str(volume), 104, 30, 1)
            bar_width = int(volume * 96 / 8)
            display.fill_rect(16, 45, bar_width, 10, 1)
            display.show()
            sleep(0.2)
        elif btn_right.value() == 0 and volume < 8:
            volume += 1
            display.fill(0)
            display.text("VOLUME", 16, 30, 1)
            display.text(str(volume), 104, 30, 1)
            bar_width = int(volume * 96 / 8)
            display.fill_rect(16, 45, bar_width, 10, 1)
            display.show()
            sleep(0.2)
        elif btn_up.value() == 0 or btn_down.value() == 0:
            save_single_setting("volume", volume)
            while btn_up.value() == 0 or btn_down.value() == 0:      
                sleep(0.05)
            return
        sleep(0.05)

# Handles octaves selection
def tone_menu():
    global tone
    display.fill(0)
    display.text("TONE", 16, 30, 1)
    display.text(str(tone), 104, 30, 1)
    bar_width = int(tone * 96 / 3)  
    display.fill_rect(16, 45, bar_width, 10, 1)
    display.show()
    while True:
        update_live_audio()
        if btn_left.value() == 0 and tone > 1:
            tone -= 1
            display.fill(0)
            display.text("TONE", 16, 30, 1)
            display.text(str(tone), 104, 30, 1)
            bar_width = int(tone * 96 / 3)  
            display.fill_rect(16, 45, bar_width, 10, 1)
            display.show()
            sleep(0.2)
        elif btn_right.value() == 0 and tone < 3:
            tone += 1
            display.fill(0)
            display.text("TONE", 16, 30, 1)
            display.text(str(tone), 104, 30, 1)
            bar_width = int(tone * 96 / 3)  
            display.fill_rect(16, 45, bar_width, 10, 1)
            display.show()
            sleep(0.2)
        elif btn_up.value() == 0 or btn_down.value() == 0:
            save_single_setting("tone", tone)
            while btn_up.value() == 0 or btn_down.value() == 0:
                sleep(0.05)
            return
        sleep(0.05)
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

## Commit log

2025-07-26 Added AUTODESK files
    includes schematic, pcb layout and library
    [PlaybackStylophone.brd, PlaybackStylophone.sch]
2025-07-26 Added software for Pico
2025-07-26 Added circuit schematic in PDF
2025-07-31 Deleted Styphone-schematic.pdf
2025-07-31 Added updated circuit schematic
2025-07-31 Updated AUTODESK files
    [PlaybackStylophone.sch]
2025-07-31 Added image of PCB layers
2025-08-11 Added PCB layers images in PNG
2025-08-12 Optimized routes layout on pcb
    [PlaybackStylophone.brd]
2025-08-12 Updated PCB images
2025-08-12 Added PCB manufacture images
2025-08-12 Added low-pass filter
    [PlaybackStylophone.brd, PlaybackStylophone.sch]
2025-08-12 Updated PCB design images
2025-08-12 Updated PCB manufacture images
2025-08-12 Updated schematic
2025-08-13 Updated schematic and pcb layout in documentation
2025-08-15 Deleted obsolete Stylophone_Schematic.pdf
    PlaybackStylophone_Schematic is the new file for schematic
2025-08-15 Deleted obsolete pcb image files
2025-08-17 Added image of PCB routes layout
2025-08-20 Added PCB tp README.md
